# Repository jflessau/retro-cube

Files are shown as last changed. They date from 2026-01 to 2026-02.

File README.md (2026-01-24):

# retro-cube

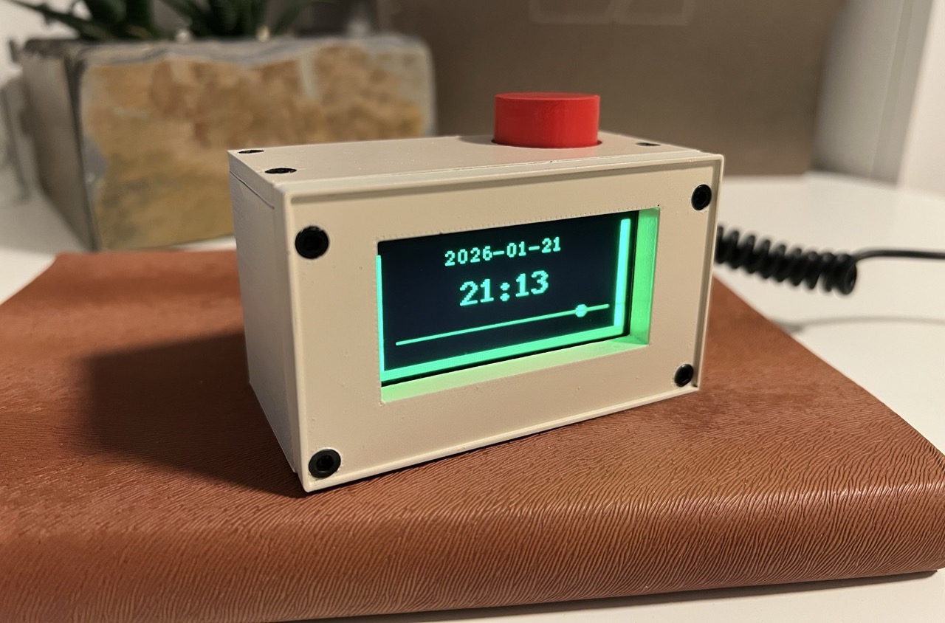
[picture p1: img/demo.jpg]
A rectangular 3D printed beige case for a OLED display showing the current time.


A 3D printable housing for a Raspberry Pi Zero W, an OLED display, and a rotary encoder.

## 🌟 Features

Use the dial to switch between views:

- **Clock** - Current date and time
- **Weather** - Current weather for your location
- **Message** - Messages loaded from a basic-auth protected server
- **Night mode** - Turns the display off and since its an OLED, no light is emitted at all

The server code is also included in this repo.

## 🔨 How to build one

### Hardware

Here is all you need:

- `1x` Rasperry Pi Zero W
- `1x` SSD1309 OLED display, **SPI**-version, 128x64, 2.4 inch, Pins at the bottom of the display, not left or right.
- `1x` GIAK KY-040 Rotary Encoder
- `12x` female-to-female jumper wires to connect the OLED to the Pi's GPIO pins
- `8x` M3 screws (5 mm head diameter, 3 mm head height, 3 mm thread diameter, 7,5 mm thread length)
- `8x` M3 inserts (see below)
- `5x` Screws to mount Pi and rotary encoder (2,5 mm thread diameter, 3-6 mm head diameter, self-tapping)
- a drop of glue to attach the 3d printed knob to the rotary encoder
- 3D printer and about 80 g of filament
- something to heat up the M3 inserts before inserting, e.g. a soldering iron

STL files for 3D printing the case can be found in `./3d/stl`.

<details>
<summary><b>M3 inserts</b></summary>
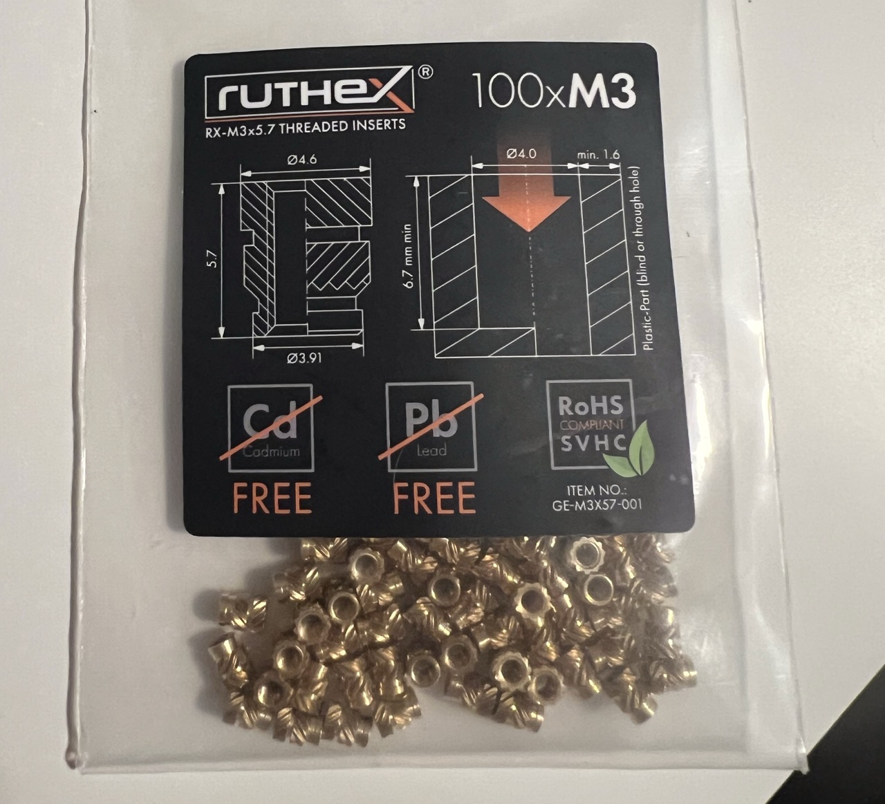
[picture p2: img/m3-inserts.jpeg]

</details>

### Wiring

This is for the Zero 2 W. Other models might have a different pinout.
Consult the manual for both the Pi and the OLED display for your specific Pi model.

<details>
<summary><b>OLED Display</b></summary>
<p>
  [Physical pin on the pi -> OLED pin]
  <ul>
    <li>6 -> GND</li>
    <li>2 -> VCC</li>
    <li>5 -> RES</li>
    <li>19 -> SDA</li>
    <li>3 -> DC</li>
    <li>23 -> SCK</li>
    <li>24 -> CS</li>
  </ul>
</p>
</details>

<details>
<summary><b>Rotary encoder</b></summary>
<p>
  [Physical pin on the pi -> Encoder pin]
  <ul>
    <li>39 -> GND</li>
    <li>1 -> VCC</li>
    <li>36 -> CLK</li>
    <li>10 -> DT</li>
    <li>8 -> SW</li>
  </ul>
</p>
</details>

### Software

The code running on the Pi is located in `./os`.
The message server is located in `./server`.

#### Server

The server serves the text message for the pi and a web form to update the text message. You can run it on the pi or any other machine the pi can reach.

To run it, rename `./server/.env.example` to `./server/.env` and set the following variables:

| Env var | Description |
| --- | --- |
| AUTH_USERNAME | Username for basic auth. Use the same here as for MESSAGE_USERNAME in `./os` |
| AUTH_PASSWORD | Password for basic auth. Use the same here as for MESSAGE_PASSWORD in `./os` |

Start it with `cargo run`. It serves on `http://localhost:3000`.

#### Os

The os service runs on the pi, controls the display, reads inputs from the rotary encoder and connects to the server to fetch the current message.

To run it on the pi, rename `./os/.env.example` to `./os/.env` and set the following variables:

| Env var | Description |
| --- | --- |
| PI_USER | Username for ssh (usually, this is just `pi`) |
| PI_IP | The IP address of your Pi |
| REFETCH_INTERVAL_SECONDS | Seconds to wait between fetching weather and message data |
| TIMEZONE | Your time zone in [IANA format](https://data.iana.org/time-zones/tzdb/zone.tab) |
| MESSAGE_URL | URL of the message server in `./server` |
| MESSAGE_USERNAME | Choose a username |
| MESSAGE_PASSWORD | Choose a password |
| WEATHER_LAT | Latitude of the location to get the weather for, e.g. `50.2` |
| WEATHER_LON | Longitude of the location to get the weather for, e.g. `12.9` |

Then run `just run-remote` which connects via ssh to your pi using the `PI_USER` and `PI_IP` variables. It builds an executable binary within docker on your machine, copies it to your pi and runs it. This step will be much nicer when you have (keybased) passwordless ssh setup with your pi.

## Development

In case you want to tinker with the software use `cargo run` for both the os and the server to run the application on your local machine.
For the os service, instead of drawing to the real OLED, this will render the OLED's content into a simulator running in a separate window.

### macOS

On macOS, you likely need to install `sdl2` to run the `./os` service, e.g. with Homebrew:

```sh
brew install sdl2
export LIBRARY_PATH="/opt/homebrew/lib:$LIBRARY_PATH"
```

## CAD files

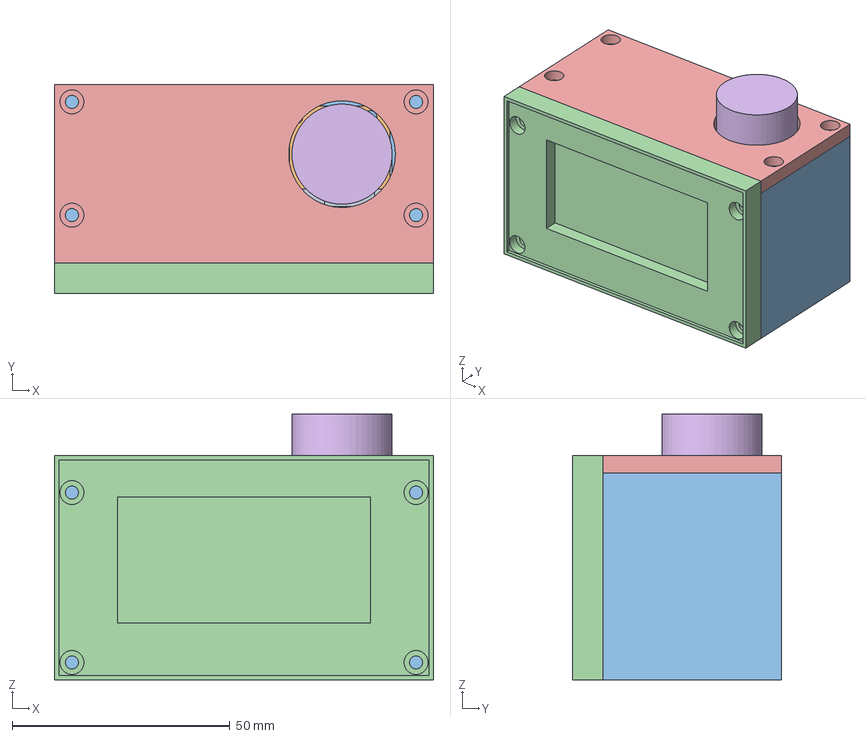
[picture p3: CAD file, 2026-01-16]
3d/case.FCStd
87.0 x 48.0 x 61.0 mm
pi
rotary encoder
panel
lid
knob

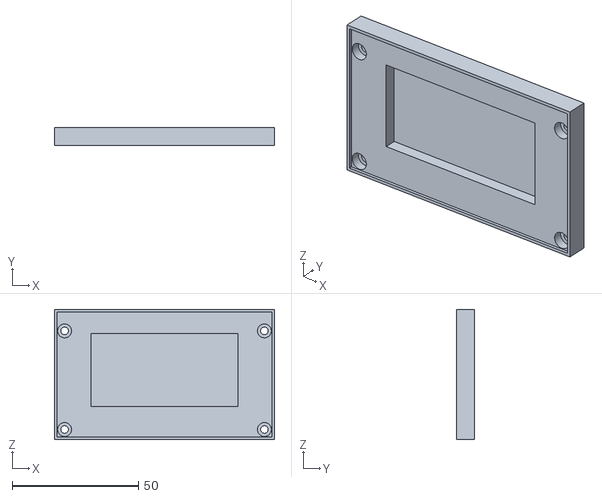
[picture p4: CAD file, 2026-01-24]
3d/stl/panel.stl
87.0 x 7.00 x 51.5

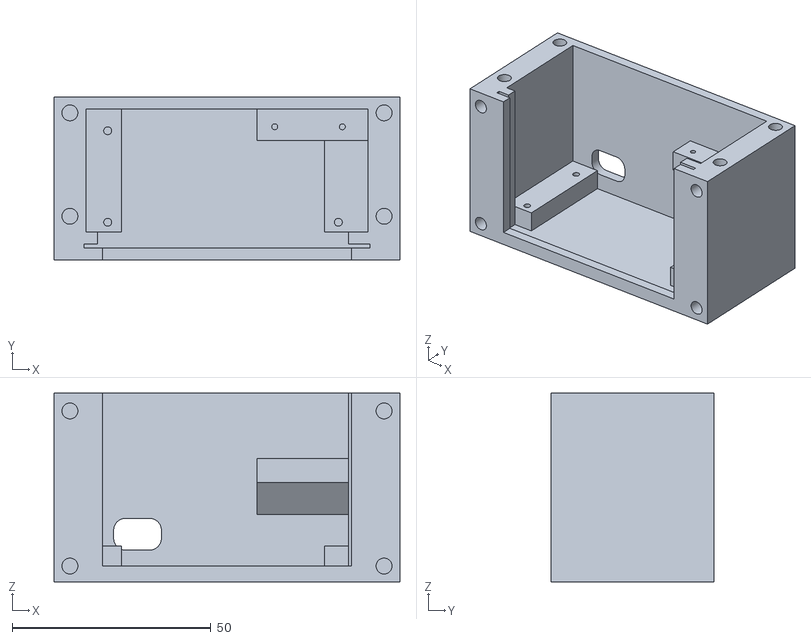
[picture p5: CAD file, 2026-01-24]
3d/stl/body.stl
87.0 x 41.0 x 47.5

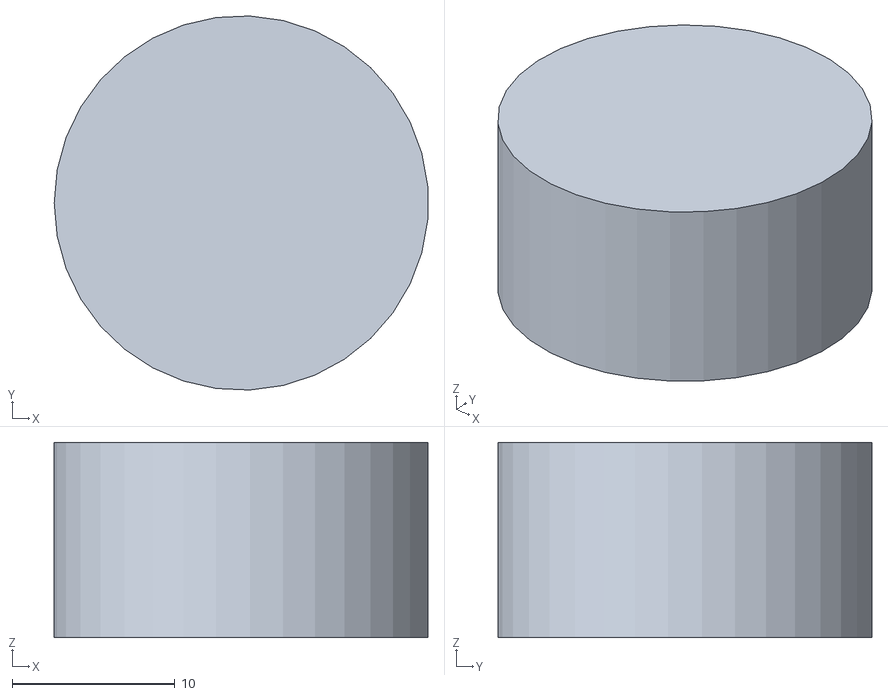
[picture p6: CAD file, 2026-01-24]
3d/stl/knob.stl
23.0 x 23.0 x 12.0

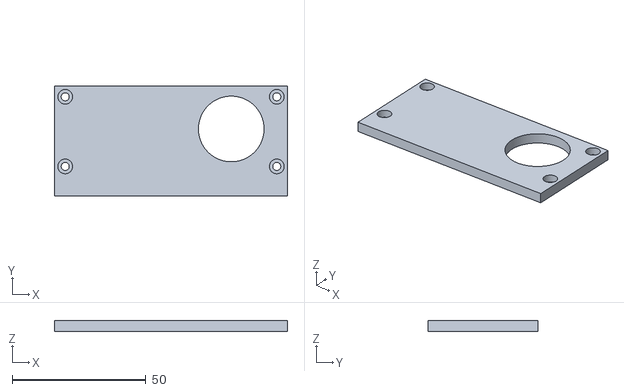
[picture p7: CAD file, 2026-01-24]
3d/stl/lid.stl
87.0 x 41.0 x 4.00

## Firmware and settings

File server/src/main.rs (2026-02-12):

use axum::{
    Form, Router,
    body::Body,
    extract::State,
    http::{Request, StatusCode, header},
    middleware::{self, Next},
    response::{Html, IntoResponse, Response},
    routing::get,
};
use base64::{Engine, engine::general_purpose::STANDARD as BASE64};
use serde::Deserialize;
use std::{env, fs, path::PathBuf, sync::Arc};
use tokio::sync::RwLock;
use tracing::{debug, info, warn};
use tracing_subscriber::prelude::*;

const MESSAGE_FILE: &str = "message.txt";
const MAX_MESSAGE_LENGTH: usize = 144;

#[derive(Clone)]
struct AppState {
    username: String,
    password: String,
    message_path: PathBuf,
    message: Arc<RwLock<String>>,
}

#[tokio::main]
async fn main() -> anyhow::Result<()> {
    dotenv::dotenv().ok();
    tracing_subscriber::registry()
        .with(tracing_subscriber::EnvFilter::new(
            env::var("RUST_LOG").unwrap_or_else(|_| "info,server=debug".into()),
        ))
        .with(tracing_subscriber::fmt::layer())
        .init();

    let username = env::var("AUTH_USERNAME").expect("AUTH_USERNAME not set");
    let password = env::var("AUTH_PASSWORD").expect("AUTH_PASSWORD not set");

    let message_path = PathBuf::from(MESSAGE_FILE);

    // Load existing message or create default
    let initial_message = if message_path.exists() {
        fs::read_to_string(&message_path).unwrap_or_else(|_| "No message yet".to_string())
    } else {
        "No message yet".to_string()
    };

    let state = AppState {
        username,
        password,
        message_path,
        message: Arc::new(RwLock::new(initial_message)),
    };

    let app = Router::new()
        .route("/", get(get_message))
        .route("/form", get(show_form).post(update_message))
        .layer(middleware::from_fn_with_state(
            state.clone(),
            auth_middleware,
        ))
        .with_state(state);

    let listener = tokio::net::TcpListener::bind("0.0.0.0:3000").await?;

    info!("Server running on http://0.0.0.0:3000");
    axum::serve(listener, app).await?;

    Ok(())
}

async fn auth_middleware(
    State(state): State<AppState>,
    req: Request<Body>,
    next: Next,
) -> Response {
    let auth_header = req
        .headers()
        .get(header::AUTHORIZATION)
        .and_then(|h| h.to_str().ok());

    if let Some(auth_value) = auth_header
        && let Some(encoded) = auth_value.strip_prefix("Basic ")
        && let Ok(decoded) = BASE64.decode(encoded)
        && let Ok(credentials) = String::from_utf8(decoded)
    {
        let parts: Vec<&str> = credentials.splitn(2, ':').collect();
        if parts.len() == 2 {
            if parts[0] == state.username && parts[1] == state.password {
                return next.run(req).await;
            } else {
                warn!(
                    "Failed authentication attempt - username: '{}', password: '{}'",
                    parts[0], parts[1]
                );
            }
        }
    }

    Response::builder()
        .status(StatusCode::UNAUTHORIZED)
        .header(header::WWW_AUTHENTICATE, "Basic realm=\"Message Server\"")
        .body(Body::from("Unauthorized"))
        .unwrap()
}

async fn get_message(State(state): State<AppState>) -> String {
    let message = state.message.read().await;
    debug!("Message read: {}", message);
    message.clone()
}

async fn show_form(State(state): State<AppState>) -> Html<String> {
    let current_message = state.message.read().await;
    let html = format!(
        r#"<!DOCTYPE html>
<html>
<head>
    <meta charset="utf-8">
    <meta name="viewport" content="width=device-width, initial-scale=1">
    <title>Update Message</title>
    <style>
        * {{
            margin: 0;
            padding: 0;
            box-sizing: border-box;
        }}
        body {{
            font-family: monospace;
            background: #000;
            color: #fff;
            padding: 20px;
            min-height: 100vh;
        }}
        .container {{
            max-width: 600px;
            margin: 0 auto;
        }}
        h1 {{
            font-size: 18px;
            font-weight: normal;
            margin-bottom: 20px;
            border-bottom: 1px solid #333;
            padding-bottom: 10px;
        }}
        form {{
            display: flex;
            flex-direction: column;
            gap: 20px;
        }}
        label {{
            display: block;
            margin-bottom: 5px;
            color: #999;
        }}
        input, textarea {{
            width: 100%;
            padding: 10px;
            background: #000;
            color: #fff;
            border: 1px solid #333;
            font-family: monospace;
            font-size: 14px;
        }}
        input:focus, textarea:focus {{
            outline: none;
            border-color: #666;
        }}
        textarea {{
            resize: vertical;
            min-height: 100px;
        }}
        button {{
            padding: 10px 20px;
            background: #fff;
            color: #000;
            border: none;
            font-family: monospace;
            cursor: pointer;
            width: fit-content;
        }}
        button:hover {{
            background: #ccc;
        }}
        .char-count {{
            text-align: right;
            font-size: 12px;
            color: #666;
            margin-top: 5px;
        }}
        .current {{
            background: #000;
            padding: 15px;
            border: 1px solid #333;
            margin-bottom: 30px;
        }}
        .current-label {{
            color: #999;
            margin-bottom: 10px;
        }}
    </style>
</head>
<body>
    <div class="container">
        <h1>update message</h1>

        <div class="current">
            <div class="current-label">current:</div>
            <div>{}</div>
        </div>

        <form method="POST" action="/form">
            <div>
                <label for="message">message (max 144 characters)</label>
                <textarea
                    id="message"
                    name="message"
                    maxlength="{}"
                    required
                    oninput="updateCharCount()"
                ></textarea>
                <div class="char-count">
                    <span id="charCount">0</span> / {} characters
                </div>
            </div>

            <button type="submit">update</button>
        </form>
    </div>

    <script>
        function updateCharCount() {{
            const textarea = document.getElementById('message');
            const charCount = document.getElementById('charCount');
            charCount.textContent = textarea.value.length;
        }}

        function filterInput(event) {{
            const textarea = event.target;
            const allowedPattern = /[a-zA-Z0-9 !,.\-#+?;:_'*\/"()]/g;
            const filtered = textarea.value.match(allowedPattern);
            const newValue = filtered ? filtered.join('') : '';

            if (newValue !== textarea.value) {{
                const cursorPos = textarea.selectionStart;
                textarea.value = newValue;
                // Try to maintain cursor position
                textarea.setSelectionRange(cursorPos - 1, cursorPos - 1);
            }}

            updateCharCount();
        }}

        document.getElementById('message').addEventListener('input', filterInput);
    </script>
</body>
</html>"#,
        html_escape(&current_message),
        MAX_MESSAGE_LENGTH,
        MAX_MESSAGE_LENGTH
    );
    Html(html)
}

#[derive(Deserialize)]
struct MessageForm {
    message: String,
}

async fn update_message(State(state): State<AppState>, Form(form): Form<MessageForm>) -> Response {
    // Validate message length
    if form.message.len() > MAX_MESSAGE_LENGTH {
        return (
            StatusCode::BAD_REQUEST,
            Html(format!(
                "<style>body{{font-family:monospace;background:#000;color:#fff;padding:20px;}}a{{color:#fff;}}</style><h1>message too long</h1><p>maximum {} characters allowed</p><a href=\"/form\">try again</a>",
                MAX_MESSAGE_LENGTH
            )),
        )
            .into_response();
    }

    let trimmed_message = form.message.trim().to_string();

    // Save to disk
    if let Err(e) = fs::write(&state.message_path, &trimmed_message) {
        return (
            StatusCode::INTERNAL_SERVER_ERROR,
            Html(format!(
                "<style>body{{font-family:monospace;background:#000;color:#fff;padding:20px;}}a{{color:#fff;}}</style><h1>error saving message</h1><p>{}</p><a href=\"/form\">try again</a>",
                e
            )),
        )
            .into_response();
    }

    // Update in-memory state
    let mut message = state.message.write().await;
    let old_message = message.clone();
    *message = trimmed_message.clone();
    info!(
        "Message changed from '{}' to '{}'",
        old_message, trimmed_message
    );

    Html(
        r#"<!DOCTYPE html>
<html>
<head>
    <meta charset="utf-8">
    <title>Message Updated</title>
    <style>
        body {
            font-family: monospace;
            background: #000;
            color: #fff;
            padding: 20px;
            max-width: 600px;
            margin: 0 auto;
        }
        .success {
            border: 1px solid #333;
            padding: 20px;
            margin-bottom: 20px;
        }
        a {
            color: #fff;
            text-decoration: none;
            padding: 10px 20px;
            background: #fff;
            color: #000;
            display: inline-block;
        }
        a:hover {
            background: #ccc;
        }
    </style>
</head>
<body>
    <div class="success">
        <h1>message updated</h1>
    </div>
    <a href="/form">update again</a>
</body>
</html>"#,
    )
    .into_response()
}

fn html_escape(s: &str) -> String {
    s.replace('&', "&amp;")
        .replace('<', "&lt;")
        .replace('>', "&gt;")
        .replace('"', "&quot;")
        .replace('\'', "&#39;")
}

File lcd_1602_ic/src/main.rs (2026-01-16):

use rppal::i2c::I2c;
use std::thread;
use std::time::Duration;

// LCD Commands
const LCD_CLEARDISPLAY: u8 = 0x01;
const LCD_ENTRYMODESET: u8 = 0x04;
const LCD_DISPLAYCONTROL: u8 = 0x08;
const LCD_FUNCTIONSET: u8 = 0x20;

// Entry Mode flags
const LCD_ENTRYLEFT: u8 = 0x02;

// Display Control flags
const LCD_DISPLAYON: u8 = 0x04;
const LCD_CURSOROFF: u8 = 0x00;
const LCD_BLINKOFF: u8 = 0x00;

// Function Set flags
const LCD_4BITMODE: u8 = 0x00;
const LCD_2LINE: u8 = 0x08;
const LCD_5X8DOTS: u8 = 0x00;

// PCF8574 pin mapping (standard)
const EN: u8 = 0b00000100; // Enable bit
const RS: u8 = 0b00000001; // Register select bit
const BACKLIGHT: u8 = 0b00001000; // Backlight bit

struct Lcd {
    i2c: I2c,
}

impl Lcd {
    fn new(address: u16) -> Result<Self, Box<dyn std::error::Error>> {
        let mut i2c = I2c::new()?;
        i2c.set_slave_address(address)?;

        let mut lcd = Lcd { i2c };
        lcd.init()?;
        Ok(lcd)
    }

    fn write_byte(&mut self, data: u8) -> Result<(), Box<dyn std::error::Error>> {
        self.i2c.write(&[data | BACKLIGHT])?;
        Ok(())
    }

    fn pulse_enable(&mut self, data: u8) -> Result<(), Box<dyn std::error::Error>> {
        self.write_byte(data | EN)?;
        thread::sleep(Duration::from_micros(1));
        self.write_byte(data & !EN)?;
        thread::sleep(Duration::from_micros(50));
        Ok(())
    }

    fn write_4bits(&mut self, data: u8) -> Result<(), Box<dyn std::error::Error>> {
        self.write_byte(data)?;
        self.pulse_enable(data)?;
        Ok(())
    }

    fn send(&mut self, data: u8, mode: u8) -> Result<(), Box<dyn std::error::Error>> {
        let high_bits = data & 0xF0;
        let low_bits = (data << 4) & 0xF0;
        self.write_4bits(high_bits | mode)?;
        self.write_4bits(low_bits | mode)?;
        Ok(())
    }

    fn command(&mut self, cmd: u8) -> Result<(), Box<dyn std::error::Error>> {
        self.send(cmd, 0)?;
        thread::sleep(Duration::from_micros(100));
        Ok(())
    }

    fn write_char(&mut self, ch: u8) -> Result<(), Box<dyn std::error::Error>> {
        self.send(ch, RS)?;
        thread::sleep(Duration::from_micros(100));
        Ok(())
    }

    fn init(&mut self) -> Result<(), Box<dyn std::error::Error>> {
        thread::sleep(Duration::from_millis(50));

        // Initialize LCD in 4-bit mode
        self.write_4bits(0x03 << 4)?;
        thread::sleep(Duration::from_millis(5));
        self.write_4bits(0x03 << 4)?;
        thread::sleep(Duration::from_micros(150));
        self.write_4bits(0x03 << 4)?;
        thread::sleep(Duration::from_micros(150));
        self.write_4bits(0x02 << 4)?;
        thread::sleep(Duration::from_micros(150));

        // Configure LCD
        self.command(LCD_FUNCTIONSET | LCD_4BITMODE | LCD_2LINE | LCD_5X8DOTS)?;
        self.command(LCD_DISPLAYCONTROL | LCD_DISPLAYON | LCD_CURSOROFF | LCD_BLINKOFF)?;
        self.clear()?;
        self.command(LCD_ENTRYMODESET | LCD_ENTRYLEFT)?;

        Ok(())
    }

    fn clear(&mut self) -> Result<(), Box<dyn std::error::Error>> {
        self.command(LCD_CLEARDISPLAY)?;
        thread::sleep(Duration::from_millis(2));
        Ok(())
    }

    fn set_cursor(&mut self, col: u8, row: u8) -> Result<(), Box<dyn std::error::Error>> {
        let row_offsets = [0x00, 0x40];
        let offset = row_offsets[row as usize] + col;
        self.command(0x80 | offset)?;
        Ok(())
    }

    fn print(&mut self, text: &str) -> Result<(), Box<dyn std::error::Error>> {
        for ch in text.chars() {
            if ch.is_ascii() {
                self.write_char(ch as u8)?;
            }
        }
        Ok(())
    }
}

fn main() -> Result<(), Box<dyn std::error::Error>> {
    // Initialize LCD at address 0x27
    let mut lcd = Lcd::new(0x27)?;

    // Clear display and write message
    lcd.clear()?;
    lcd.print("hello world")?;

    // Write to second line
    lcd.set_cursor(0, 1)?;
    lcd.print("LCD working!")?;

    println!("✅ 'hello world' written to LCD1602!");

    Ok(())
}

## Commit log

2026-01-06 feature: support rotary encoder
2026-01-16 wip: connect lcd_16_02_ic
    [case-26.FCStd, case-v2-17.FCStd]
2026-01-21 fix: display orientation
    [case-26.FCStd, case.FCStd]
2026-01-24 doc: add video to readme
    [body.stl, knob.stl, lid.stl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]
2026-01-24 doc: add screws for mounting pi and encoder
2026-02-12 fix: rm chars in the message not covered by font
    [main.rs]
